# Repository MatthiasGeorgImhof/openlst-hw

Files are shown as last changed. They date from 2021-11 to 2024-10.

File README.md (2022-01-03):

$1K CubeSat Design
==========================

This forked repo adapts the hardware from the OpenLST Reference into something that works for my $1K CubeSat project

**Please note that this repository is desgined to be used as a submodule**, since it depends on symbols & footprints in my [1KCubeSat_Hardware repository](https://github.com/rgw3d/1KCubeSat_Hardware)

Overview
--------

This is an iteration on the OpenLST CC1110 based design, which itself is a simplified version of the TI CC1110 432 MHz reference design.
While the CC1110 can operate over 400-470MHz, this board is designed to operate around 435MHz, within the 435MHz-438MHz US Amateur radio band.
See the [FCC's chart, specifically section 5.282](https://transition.fcc.gov/oet/spectrum/table/fcctable.pdf)

* [Schematic](pdf/openlst-hw.pdf) in PDF form
* [Bill of materials](bom/) with ordering information & datasheet links
* [Gerber files](gerber/osh_park) for PCB fabrication

RF Pipeline
-----------

* **0433BM15A0001 Balun**. Designed for 430-435MHz, but should work up to 437MHz. Single part, designed specifically for the CC1110. I did not want to design my own balun.
* **PE4250MLI RF Switch**. Generic SPDT RF Switch. First RF switch breaks out to a test port. Second RF switch switches between TX & RX paths on the RF Frontend (RFFM6403).
* **RFFM6403 Analog Frontend**. TX path with 1.5W PA, RX path with LNA & SAW filter. Designed to work over the 408-455MHz band.
* **SF2446E SAW Filter**. Part of the Analog Frontend RX path. 430-440MHz band pass.
* 50 Ohm
* Impedance calculations for OSH Park PCB found [here](images/osh-park-4-layer-50ohms.png)

Design Verification
--------

Initial testing has verified basic functionality.

* 437MHz reference software from the [OpenLST Software repo](https://github.com/rgw3d/openlst) is able to be flashed onto the CC1110. NOTE: CC1110 PA output power was modified from 10dBm to 0dBm.
* The 3.3V rail consumes 130mA to 150mA. One board indicated 130mA, another one had 150mA, unsure what causes the discrepency.
* The 27MHz clipped sine wave oscillator works as a clock source
* The RF pipeline is functional. Both the test output (J8) and the RF Frontend output (J9) function.
* Radio-to-radio communication with test outputs connected. Communication was initiated using UART1 on Board 1.
  * (J8, Board 1)---(coax)---(30dBm attenuator)---(coax)---(J8, Board 2)
* Radio-to-radio communication with RF Frontend outputs connected. Communication was initiated using UART1 on Board 1.
  * (J9, Board 1)---(coax)---(three 30dBm attenuators)---(coax)---(J9, Board 2)
* At this time no RF performance characteristics were measured. (I don't have the lab equipment for those tests)

Improvements for future version
--------

* Pi network at output of RF Frontend. Could be useful to match an antenna.
* Better 3.3V LDO. For a bench top setup, U1 (ADP150-3.3V) can just supply 150mA. While this design assumes an external 3.3V source, this on-board convenience ought to be sized up.
* Ferrite beads or 0Ohm Resistors on power inputs to all components. During assembly for one of the boards, a short was detected on the 3.3V rail. Several components share that rail without an easy way to open it, which would have made isolating the problem simple.

Pictures
--------

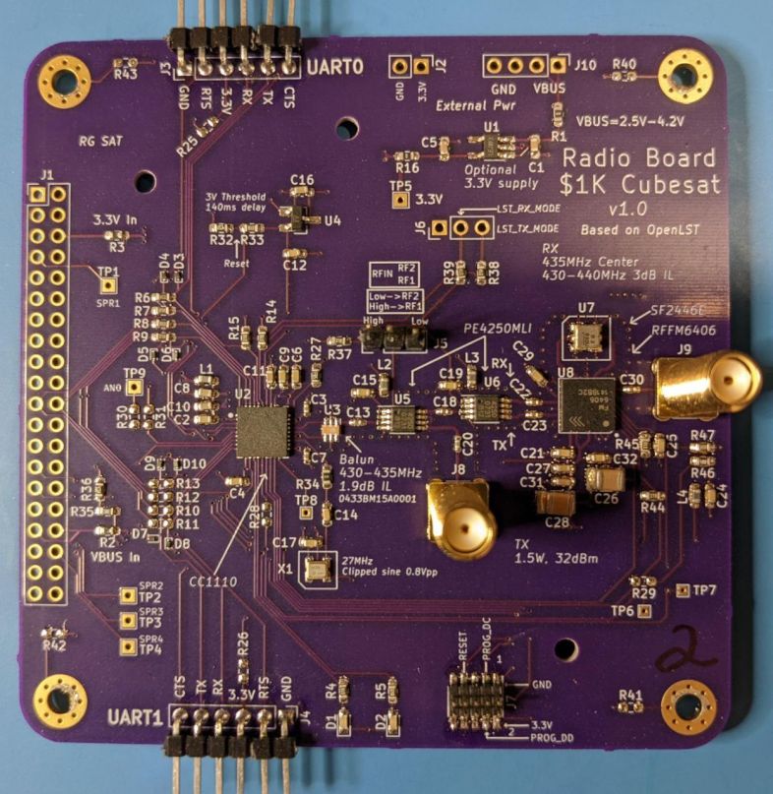
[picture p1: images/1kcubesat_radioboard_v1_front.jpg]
1KCubesat RadioBoard V1 Front

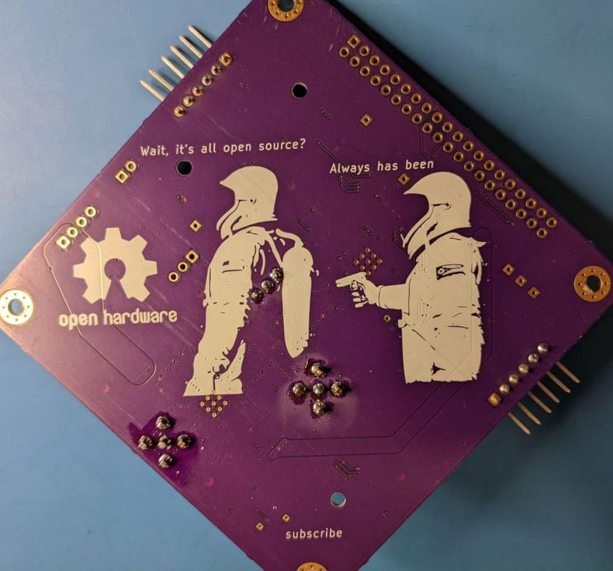
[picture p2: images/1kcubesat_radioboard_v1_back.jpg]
1KCubesat RadioBoard V1 Back


Original README below

OpenLST Reference Hardware
==========================

This repository contains a KiCad project with a hardware reference
implementation for the OpenLST.  This design is a simplified version
of the Texas Instruments CC1110 432 MHz reference design.  A 1 watt
power amplifier module has been added to increase operating range.
The design is intended for use at 437 MHz, however, it may be modified
for use at other frequencies.

The user is responsible for obtaining and maintaining the necessary
license to operate this radio.  The example project uses frequencies
in the US Amateur Radio UHF band. Transmissions in this band require a
valid FCC license and compliance with CFR Part 97.

License & Legal Information
---------------------------

Copyright 2018 Planet Labs Inc. This work is licensed under a
Creative Commons Attribution-ShareAlike 4.0 International License.

This document may contain technology or software the export of which
is or may be restricted by the Export Administration Act and the
Export Administration Regulations (EAR), 15 C.F.R. parts
730-774. Diversion contrary to U.S. law is prohibited.

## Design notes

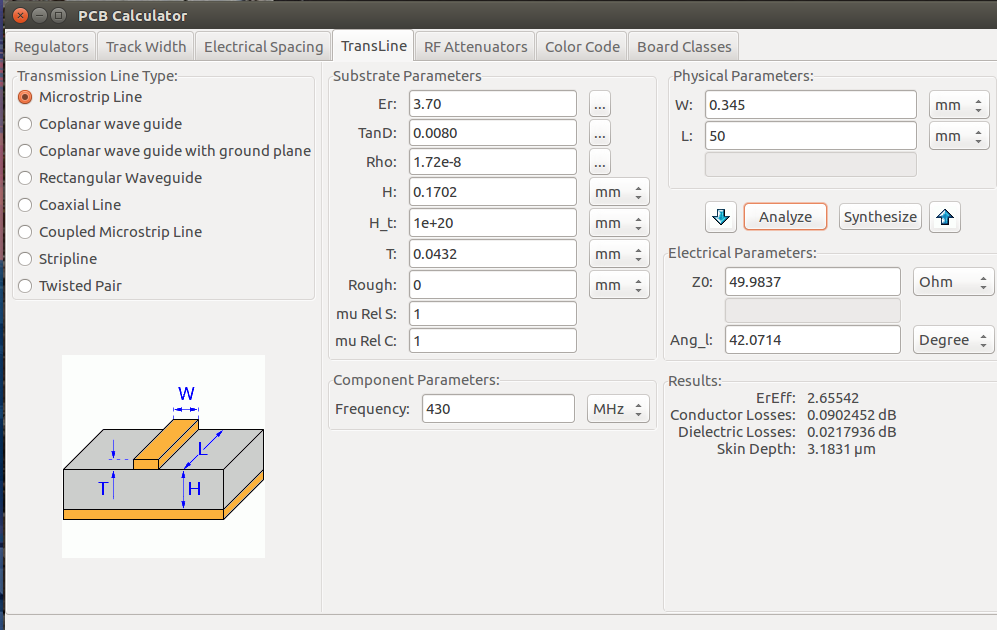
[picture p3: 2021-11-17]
images/osh-park-4-layer-50ohms.png

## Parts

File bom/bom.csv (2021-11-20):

Source: | /home/rgw3d/1KCubeSat_Hardware/openlst-hw/openlst-hw.sch
Date: | Tue 16 Nov 2021 11:39:37 PM EST
Tool: | Eeschema 5.1.7-a382d34a8~88~ubuntu16.04.1
Component Count: | 108
Ref | Value | Part | Footprint | Description | Vendor
C1 | 4.7uF | Device:C_Small | Capacitor_SMD:C_0603_1608Metric_Pad1.08x0.95mm_HandSolder | Unpolarized capacitor, small symbol
C2 | 0.1uF | Device:C_Small | Capacitor_SMD:C_0603_1608Metric_Pad1.08x0.95mm_HandSolder | Unpolarized capacitor, small symbol
C3 | 220pF | openlst-hw:C_Small | Capacitor_SMD:C_0402_1005Metric_Pad0.74x0.62mm_HandSolder
C4 | 0.1uF | Device:C_Small | Capacitor_SMD:C_0603_1608Metric_Pad1.08x0.95mm_HandSolder | Unpolarized capacitor, small symbol
C5 | 4.7uF | Device:C_Small | Capacitor_SMD:C_0603_1608Metric_Pad1.08x0.95mm_HandSolder | Unpolarized capacitor, small symbol
C6 | 0.1uF | Device:C_Small | Capacitor_SMD:C_0603_1608Metric_Pad1.08x0.95mm_HandSolder | Unpolarized capacitor, small symbol
C7 | 220pF | openlst-hw:C_Small | Capacitor_SMD:C_0402_1005Metric_Pad0.74x0.62mm_HandSolder
C8 | 1uF | Device:C_Small | Capacitor_SMD:C_0603_1608Metric_Pad1.08x0.95mm_HandSolder | Unpolarized capacitor, small symbol
C9 | 0.1uF | Device:C_Small | Capacitor_SMD:C_0603_1608Metric_Pad1.08x0.95mm_HandSolder | Unpolarized capacitor, small symbol
C10 | 1uF | Device:C_Small | Capacitor_SMD:C_0603_1608Metric_Pad1.08x0.95mm_HandSolder | Unpolarized capacitor, small symbol
C11 | 1uF | Device:C_Small | Capacitor_SMD:C_0603_1608Metric_Pad1.08x0.95mm_HandSolder | Unpolarized capacitor, small symbol
C12 | 0.01uF | Device:C_Small | Capacitor_SMD:C_0603_1608Metric_Pad1.08x0.95mm_HandSolder | Unpolarized capacitor, small symbol
C13 | 220pF | openlst-hw:C_Small | Capacitor_SMD:C_0402_1005Metric_Pad0.74x0.62mm_HandSolder
C14 | 0.01uF | Device:C_Small | Capacitor_SMD:C_0603_1608Metric_Pad1.08x0.95mm_HandSolder | Unpolarized capacitor, small symbol
C15 | 0.1uF | Device:C_Small | Capacitor_SMD:C_0603_1608Metric_Pad1.08x0.95mm_HandSolder | Unpolarized capacitor, small symbol
C16 | 0.1uF | Device:C_Small | Capacitor_SMD:C_0603_1608Metric_Pad1.08x0.95mm_HandSolder | Unpolarized capacitor, small symbol
C17 | 0.1uF | Device:C_Small | Capacitor_SMD:C_0603_1608Metric_Pad1.08x0.95mm_HandSolder | Unpolarized capacitor, small symbol
C18 | 220pF | openlst-hw:C_Small | Capacitor_SMD:C_0402_1005Metric_Pad0.74x0.62mm_HandSolder
C19 | 0.1uF | Device:C_Small | Capacitor_SMD:C_0603_1608Metric_Pad1.08x0.95mm_HandSolder | Unpolarized capacitor, small symbol
C20 | 220pF | openlst-hw:C_Small | Capacitor_SMD:C_0402_1005Metric_Pad0.74x0.62mm_HandSolder
C21 | 0.1uF | Device:C_Small | Capacitor_SMD:C_0603_1608Metric_Pad1.08x0.95mm_HandSolder | Unpolarized capacitor, small symbol
C22 | 220pF | openlst-hw:C_Small | Capacitor_SMD:C_0402_1005Metric_Pad0.74x0.62mm_HandSolder
C23 | 220pF | openlst-hw:C_Small | Capacitor_SMD:C_0402_1005Metric_Pad0.74x0.62mm_HandSolder
C24 | 0.1uF | Device:C_Small | Capacitor_SMD:C_0603_1608Metric_Pad1.08x0.95mm_HandSolder | Unpolarized capacitor, small symbol
C25 | 0.1uF | Device:C_Small | Capacitor_SMD:C_0603_1608Metric_Pad1.08x0.95mm_HandSolder | Unpolarized capacitor, small symbol
C26 | 47uF | Device:C | Capacitor_SMD:C_1210_3225Metric_Pad1.33x2.70mm_HandSolder | Unpolarized capacitor
C27 | 1uF | Device:C_Small | Capacitor_SMD:C_0603_1608Metric_Pad1.08x0.95mm_HandSolder | Unpolarized capacitor, small symbol
C28 | 47uF | Device:C | Capacitor_SMD:C_1210_3225Metric_Pad1.33x2.70mm_HandSolder | Unpolarized capacitor
C29 | 0.1uF | Device:C_Small | Capacitor_SMD:C_0603_1608Metric_Pad1.08x0.95mm_HandSolder | Unpolarized capacitor, small symbol
C30 | 220pF | openlst-hw:C_Small | Capacitor_SMD:C_0402_1005Metric_Pad0.74x0.62mm_HandSolder
C31 | 4.7uF | Device:C_Small | Capacitor_SMD:C_0603_1608Metric_Pad1.08x0.95mm_HandSolder | Unpolarized capacitor, small symbol
C32 | 0.1uF | Device:C_Small | Capacitor_SMD:C_0603_1608Metric_Pad1.08x0.95mm_HandSolder | Unpolarized capacitor, small symbol
D1 | LED_SMD_RED | Device:LED_Small_ALT | LED_SMD:LED_0603_1608Metric_Pad1.05x0.95mm_HandSolder | Light emitting diode, small symbol, filled shape
D2 | LED_SMD_RED | Device:LED_Small_ALT | LED_SMD:LED_0603_1608Metric_Pad1.05x0.95mm_HandSolder | Light emitting diode, small symbol, filled shape
D3 | ESD9B5.0ST5G | Diode:ESD9B5.0ST5G | Diode_SMD:D_SOD-923 | ESD protection diode, 5.0Vrwm, SOD-923
D4 | ESD9B5.0ST5G | Diode:ESD9B5.0ST5G | Diode_SMD:D_SOD-923 | ESD protection diode, 5.0Vrwm, SOD-923
D5 | ESD9B5.0ST5G | Diode:ESD9B5.0ST5G | Diode_SMD:D_SOD-923 | ESD protection diode, 5.0Vrwm, SOD-923
D6 | ESD9B5.0ST5G | Diode:ESD9B5.0ST5G | Diode_SMD:D_SOD-923 | ESD protection diode, 5.0Vrwm, SOD-923
D7 | ESD9B5.0ST5G | Diode:ESD9B5.0ST5G | Diode_SMD:D_SOD-923 | ESD protection diode, 5.0Vrwm, SOD-923
D8 | ESD9B5.0ST5G | Diode:ESD9B5.0ST5G | Diode_SMD:D_SOD-923 | ESD protection diode, 5.0Vrwm, SOD-923
D9 | ESD9B5.0ST5G | Diode:ESD9B5.0ST5G | Diode_SMD:D_SOD-923 | ESD protection diode, 5.0Vrwm, SOD-923
D10 | ESD9B5.0ST5G | Diode:ESD9B5.0ST5G | Diode_SMD:D_SOD-923 | ESD protection diode, 5.0Vrwm, SOD-923
H1 | MountingHole_Pad | Mechanical:MountingHole_Pad | MountingHole:MountingHole_3.2mm_M3_Pad_Via | Mounting Hole with connection
H2 | MountingHole_Pad | Mechanical:MountingHole_Pad | MountingHole:MountingHole_3.2mm_M3_Pad_Via | Mounting Hole with connection
H3 | MountingHole_Pad | Mechanical:MountingHole_Pad | MountingHole:MountingHole_3.2mm_M3_Pad_Via | Mounting Hole with connection
H4 | MountingHole_Pad | Mechanical:MountingHole_Pad | MountingHole:MountingHole_3.2mm_M3_Pad_Via | Mounting Hole with connection
J1 | Conn_02x20_Odd_Even | Connector_Generic:Conn_02x20_Odd_Even | Connector_PinHeader_2.54mm:PinHeader_2x20_P2.54mm_Vertical | Generic connector, double row, 02x20, odd/even pin numbering scheme (row 1 odd numbers, row 2 even numbers), script generated (kicad-library-utils/schlib/autogen/connector/)
J2 | EXT 3.3V | Connector_Generic:Conn_01x02 | Connector_PinHeader_2.54mm:PinHeader_1x02_P2.54mm_Vertical | Generic connector, single row, 01x02, script generated (kicad-library-utils/schlib/autogen/connector/)
J3 | UART0 | Connector_Generic:Conn_01x06 | Connector_PinHeader_2.54mm:PinHeader_1x06_P2.54mm_Vertical | Generic connector, single row, 01x06, script generated (kicad-library-utils/schlib/autogen/connector/)
J4 | UART1 | Connector_Generic:Conn_01x06 | Connector_PinHeader_2.54mm:PinHeader_1x06_P2.54mm_Vertical | Generic connector, single row, 01x06, script generated (kicad-library-utils/schlib/autogen/connector/)
J5 | Switch Select | Connector_Generic:Conn_01x03 | Connector_PinHeader_2.54mm:PinHeader_1x03_P2.54mm_Vertical | Generic connector, single row, 01x03, script generated (kicad-library-utils/schlib/autogen/connector/)
J6 | Control Outputs | Connector_Generic:Conn_01x03 | Connector_PinHeader_2.54mm:PinHeader_1x03_P2.54mm_Vertical | Generic connector, single row, 01x03, script generated (kicad-library-utils/schlib/autogen/connector/)
J7 | CC Prog/Debug | Connector_Generic:Conn_02x05_Odd_Even | Connector_PinHeader_1.27mm:PinHeader_2x05_P1.27mm_Vertical_SMD | Generic connector, double row, 02x05, odd/even pin numbering scheme (row 1 odd numbers, row 2 even numbers), script generated (kicad-library-utils/schlib/autogen/connector/)
J8 | Conn_Coaxial | Connector:Conn_Coaxial | Connector_Coaxial:SMA_Amphenol_901-144_Vertical | coaxial connector (BNC, SMA, SMB, SMC, Cinch/RCA, ...)
J9 | ANT | Connector:Conn_Coaxial | Connector_Coaxial:SMA_Amphenol_901-144_Vertical | coaxial connector (BNC, SMA, SMB, SMC, Cinch/RCA, ...)
J10 | EXT VBUS | Connector_Generic:Conn_01x04 | Connector_PinHeader_2.54mm:PinHeader_1x04_P2.54mm_Vertical | Generic connector, single row, 01x04, script generated (kicad-library-utils/schlib/autogen/connector/)
L1 | Z=1k @ 100M | openlst-hw:Ferrite_Bead | Inductor_SMD:L_0603_1608Metric_Pad1.05x0.95mm_HandSolder
L2 | Z=1k @ 100M | openlst-hw:Ferrite_Bead | Inductor_SMD:L_0603_1608Metric_Pad1.05x0.95mm_HandSolder
L3 | Z=1k @ 100M | openlst-hw:Ferrite_Bead | Inductor_SMD:L_0603_1608Metric_Pad1.05x0.95mm_HandSolder
L4 | Z=1k @ 100M | openlst-hw:Ferrite_Bead | Inductor_SMD:L_0603_1608Metric_Pad1.05x0.95mm_HandSolder
R1 | DNP | Device:R | Resistor_SMD:R_0603_1608Metric_Pad0.98x0.95mm_HandSolder | Resistor
R2 | 10m | Device:R | Resistor_SMD:R_0603_1608Metric_Pad0.98x0.95mm_HandSolder | Resistor
R3 | 10m | Device:R | Resistor_SMD:R_0603_1608Metric_Pad0.98x0.95mm_HandSolder | Resistor
R4 | 1K | Device:R | Resistor_SMD:R_0603_1608Metric_Pad0.98x0.95mm_HandSolder | Resistor
R5 | 1K | Device:R | Resistor_SMD:R_0603_1608Metric_Pad0.98x0.95mm_HandSolder | Resistor
R6 | 100 | openlst-hw:R | Resistor_SMD:R_0603_1608Metric_Pad0.98x0.95mm_HandSolder
R7 | 100 | openlst-hw:R | Resistor_SMD:R_0603_1608Metric_Pad0.98x0.95mm_HandSolder
R8 | 100 | openlst-hw:R | Resistor_SMD:R_0603_1608Metric_Pad0.98x0.95mm_HandSolder
R9 | 100 | openlst-hw:R | Resistor_SMD:R_0603_1608Metric_Pad0.98x0.95mm_HandSolder
R10 | DNP | Device:R | Resistor_SMD:R_0603_1608Metric_Pad0.98x0.95mm_HandSolder | Resistor
R11 | DNP | Device:R | Resistor_SMD:R_0603_1608Metric_Pad0.98x0.95mm_HandSolder | Resistor
R12 | DNP | Device:R | Resistor_SMD:R_0603_1608Metric_Pad0.98x0.95mm_HandSolder | Resistor
R13 | DNP | Device:R | Resistor_SMD:R_0603_1608Metric_Pad0.98x0.95mm_HandSolder | Resistor
R14 | 1K | Device:R | Resistor_SMD:R_0603_1608Metric_Pad0.98x0.95mm_HandSolder | Resistor
R15 | 1K | Device:R | Resistor_SMD:R_0603_1608Metric_Pad0.98x0.95mm_HandSolder | Resistor
R16 | 0 | Device:R | Resistor_SMD:R_0603_1608Metric_Pad0.98x0.95mm_HandSolder | Resistor
R25 | DNP | Device:R | Resistor_SMD:R_0603_1608Metric_Pad0.98x0.95mm_HandSolder | Resistor
R26 | DNP | Device:R | Resistor_SMD:R_0603_1608Metric_Pad0.98x0.95mm_HandSolder | Resistor
R27 | 56K | openlst-hw:R | Resistor_SMD:R_0603_1608Metric_Pad0.98x0.95mm_HandSolder
R28 | DNP | Device:R | Resistor_SMD:R_0603_1608Metric_Pad0.98x0.95mm_HandSolder | Resistor
R29 | DNP | Device:R | Resistor_SMD:R_0603_1608Metric_Pad0.98x0.95mm_HandSolder | Resistor
R30 | DNP | Device:R | Resistor_SMD:R_0603_1608Metric_Pad0.98x0.95mm_HandSolder | Resistor
R31 | DNP | Device:R | Resistor_SMD:R_0603_1608Metric_Pad0.98x0.95mm_HandSolder | Resistor
R32 | 47K | Device:R | Resistor_SMD:R_0603_1608Metric_Pad0.98x0.95mm_HandSolder | Resistor
R33 | 1K | Device:R | Resistor_SMD:R_0603_1608Metric_Pad0.98x0.95mm_HandSolder | Resistor
R34 | 0 | Device:R | Resistor_SMD:R_0603_1608Metric_Pad0.98x0.95mm_HandSolder | Resistor
R35 | 20K | Device:R | Resistor_SMD:R_0603_1608Metric_Pad0.98x0.95mm_HandSolder | Resistor
R36 | 47K | Device:R | Resistor_SMD:R_0603_1608Metric_Pad0.98x0.95mm_HandSolder | Resistor
R37 | 1K | Device:R | Resistor_SMD:R_0603_1608Metric_Pad0.98x0.95mm_HandSolder | Resistor
R38 | 100 | openlst-hw:R | Resistor_SMD:R_0603_1608Metric_Pad0.98x0.95mm_HandSolder
R39 | 100 | openlst-hw:R | Resistor_SMD:R_0603_1608Metric_Pad0.98x0.95mm_HandSolder
R40 | DNP | Device:R | Resistor_SMD:R_0603_1608Metric_Pad0.98x0.95mm_HandSolder | Resistor
R41 | DNP | Device:R | Resistor_SMD:R_0603_1608Metric_Pad0.98x0.95mm_HandSolder | Resistor
R42 | DNP | Device:R | Resistor_SMD:R_0603_1608Metric_Pad0.98x0.95mm_HandSolder | Resistor
R43 | DNP | Device:R | Resistor_SMD:R_0603_1608Metric_Pad0.98x0.95mm_HandSolder | Resistor
R44 | 1K | Device:R | Resistor_SMD:R_0603_1608Metric_Pad0.98x0.95mm_HandSolder | Resistor
R45 | 1K | Device:R | Resistor_SMD:R_0603_1608Metric_Pad0.98x0.95mm_HandSolder | Resistor
R46 | 3.09K | Device:R | Resistor_SMD:R_0603_1608Metric_Pad0.98x0.95mm_HandSolder | Resistor
R47 | 6.65K | Device:R | Resistor_SMD:R_0603_1608Metric_Pad0.98x0.95mm_HandSolder | Resistor
U1 | ADP150AUJZ-3.3-R7 | 1K_Custom_Symbol:ADP150AUJZ-3.3-R7 | Package_TO_SOT_SMD:TSOT-23-5_HandSoldering
U2 | CC1110 | openlst-hw:CC1110 | openlst:TI_CC_QFN36
U3 | 0433BM15A0001 | Transformer:0433BM15A0001 | RF_Converter:Balun_Johanson_0896BM15A0001 | 430-435MHz 1:1 RF Transformer, Unbalanced to Balanced, with integrated DC blocking capacitor
U4 | MIC803 | 1K_Custom_Symbol:MIC803 | Package_TO_SOT_SMD:SOT-23_Handsoldering
U5 | PE4250MLI | 1K_Custom_Symbol:PE4250MLI | Package_SO:MSOP-8_3x3mm_P0.65mm
U6 | PE4250MLI | 1K_Custom_Symbol:PE4250MLI | Package_SO:MSOP-8_3x3mm_P0.65mm
U7 | SF2446E | 1K_Custom_Symbol:SF2446E | footprint_custom:SF2446E | SAW filter 435MHz
U8 | RFFM6406 | 1K_Custom_Symbol:RFFM6406 | openlst:Qorvo_LGA_28_ThermalVias | Copy of RFFM6403 Symbol from OpenLST Reference
X1 | TG2520SMN 27MHz | 1K_Custom_Symbol:TG2520SMN | footprint_custom:TG2520SMN | 27MHz TCXO Clipped Sine Wave Oscillator 2.8V-3.3V 4-SMD, No Lead

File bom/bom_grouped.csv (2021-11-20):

Reference | Quantity | Value | Footprint | Datasheet | Manuf | ManufPN | Supplier | SupplierPN | Order | Size | Mfr. # | Voltage
C1 C5 C31 | 3 | 4.7uF | Capacitor_SMD:C_0603_1608Metric_Pad1.08x0.95mm_HandSolder | ~ |  |  |  |  |  | 0603 |  | 10V
C12 C14 | 2 | 0.01uF | Capacitor_SMD:C_0603_1608Metric_Pad1.08x0.95mm_HandSolder | ~ |  |  |  |  | https://www.digikey.com/en/products/detail/samsung-electro-mechanics/CL10B103KB8NNNC/3886667 |  | CL10B103KB8NNNC | 50V
C2 C4 C6 C9 C15 C16 C17 C19 C21 C24 C25 C29 C32 | 13 | 0.1uF | Capacitor_SMD:C_0603_1608Metric_Pad1.08x0.95mm_HandSolder | ~ |  |  |  |  | https://www.digikey.com/product-detail/en/samsung-electro-mechanics/CL10B104KA8NNNC/1276-1006-1-ND/3889092 |  | CL10B104KA8NNNC | 25V
C26 C28 | 2 | 47uF | Capacitor_SMD:C_1210_3225Metric_Pad1.33x2.70mm_HandSolder | ~ |  |  |  |  | https://www.digikey.com/product-detail/en/murata-electronics/GRM32EC81C476KE15L/490-10531-1-ND/5026469 | 1210 | GRM32EC81C476KE15L | 16V
C3 C7 C13 C18 C20 C22 C23 C30 | 8 | 220pF | Capacitor_SMD:C_0402_1005Metric_Pad0.74x0.62mm_HandSolder | https://api.kemet.com/component-edge/download/datasheet/C0402C221J2GACAUTO.pdf | Kemet | C0402C221J2GACAUTO | Digikey | 399-11552-1-ND |  | 0402 |  | 200V
C8 C10 C11 C27 | 4 | 1uF | Capacitor_SMD:C_0603_1608Metric_Pad1.08x0.95mm_HandSolder | ~ |  |  |  |  | https://www.digikey.com/product-detail/en/samsung-electro-mechanics/CL10B105KP8NFNC/1276-1945-1-ND/3890031 |  | CL10B105KP8NFNC | 10V
D1 D2 | 2 | LED_SMD_RED | LED_SMD:LED_0603_1608Metric_Pad1.05x0.95mm_HandSolder | https://katalog.we-online.de/led/datasheet/150060RS75000.pdf |  |  |  |  | https://www.digikey.com/product-detail/en/w%C3%BCrth-elektronik/150060RS75000/732-4978-1-ND/4489899 |  | 150060RS75000
D3 D4 D5 D6 D7 D8 D9 D10 | 8 | ESD9B5.0ST5G | Diode_SMD:D_SOD-923 | https://www.onsemi.com/pub/Collateral/ESD9B-D.PDF |  |  |  |  | https://www.digikey.com/product-detail/en/on-semiconductor/ESD9B5-0ST5G/ESD9B5-0ST5GOSCT-ND/1646497 |  | ESD9B5.0ST5G
H1 H2 H3 H4 | 4 | MountingHole_Pad | MountingHole:MountingHole_3.2mm_M3_Pad_Via | ~
J1 | 1 | Conn_02x20_Odd_Even | Connector_PinHeader_2.54mm:PinHeader_2x20_P2.54mm_Vertical | ~ |  |  |  |  | https://www.digikey.com/product-detail/en/samtec-inc/ESQ-120-13-T-D/ESQ-120-13-T-D-ND/7098677 |  | ESQ-120-13-T-D
J10 | 1 | EXT VBUS | Connector_PinHeader_2.54mm:PinHeader_1x04_P2.54mm_Vertical | ~
J2 | 1 | EXT 3.3V | Connector_PinHeader_2.54mm:PinHeader_1x02_P2.54mm_Vertical | ~
J3 | 1 | UART0 | Connector_PinHeader_2.54mm:PinHeader_1x06_P2.54mm_Vertical | ~
J4 | 1 | UART1 | Connector_PinHeader_2.54mm:PinHeader_1x06_P2.54mm_Vertical | ~
J5 | 1 | Switch Select | Connector_PinHeader_2.54mm:PinHeader_1x03_P2.54mm_Vertical | ~
J6 | 1 | Control Outputs | Connector_PinHeader_2.54mm:PinHeader_1x03_P2.54mm_Vertical
J7 | 1 | CC Prog/Debug | Connector_PinHeader_1.27mm:PinHeader_2x05_P1.27mm_Vertical_SMD | https://app.adam-tech.com/products/download/data_sheet/199937/hph2-a-xx-ua-smt-data-sheet.pdf |  |  |  |  | https://www.digikey.com/en/products/detail/adam-tech/HPH2-A-10-UA-SMT/9831541 |  | HPH2-A-10-UA-SMT
J8 | 1 | Conn_Coaxial | Connector_Coaxial:SMA_Amphenol_901-144_Vertical | https://s3-us-west-2.amazonaws.com/catsy.582/C901-144-8RFX.pdf |  |  |  |  | https://www.digikey.com/en/products/detail/amphenol-rf/901-144-8RFX/272189 |  | 901-144-8RFX
J9 | 1 | ANT | Connector_Coaxial:SMA_Amphenol_901-144_Vertical | https://s3-us-west-2.amazonaws.com/catsy.582/C901-144-8RFX.pdf |  |  |  |  | https://www.digikey.com/en/products/detail/amphenol-rf/901-144-8RFX/272189 |  | 901-144-8RFX
L1 L2 L3 L4 | 4 | Z=1k @ 100M | Inductor_SMD:L_0603_1608Metric_Pad1.05x0.95mm_HandSolder | http://katalog.we-online.de/pbs/datasheet/74279266.pdf |  |  |  |  | https://www.digikey.com/en/products/detail/murata-electronics/BLM18AG102SN1D/584226 |  | BLM18AG102SN1D
R16 R34 | 2 | 0 | Resistor_SMD:R_0603_1608Metric_Pad0.98x0.95mm_HandSolder | ~ |  |  |  |  |  | 0603
R2 R3 | 2 | 10m | Resistor_SMD:R_0603_1608Metric_Pad0.98x0.95mm_HandSolder | ~ |  |  |  |  | https://www.digikey.com/product-detail/en/panasonic-electronic-components/ERJ-3LWJR010V/P19190CT-ND/6004545 | 0603 | ERJ-3LWJR010V
R27 | 1 | 56K | Resistor_SMD:R_0603_1608Metric_Pad0.98x0.95mm_HandSolder | https://www.seielect.com/Catalog/SEI-RMCF_RMCP.pdf | YAGEO | RC0603JR-0756KL | Digikey | 311-56KGRCT-ND | https://www.digikey.com/en/products/detail/yageo/RC0603JR-0756KL/726808 | 0603
R32 R36 | 2 | 47K | Resistor_SMD:R_0603_1608Metric_Pad0.98x0.95mm_HandSolder | https://www.bourns.com/docs/Product-Datasheets/CHPREZTR.pdf |  |  |  |  | https://www.digikey.com/product-detail/en/bourns-inc/CR0603-FX-4702ELF/CR0603-FX-4702ELFCT-ND/3925317 | 0603 | CR0603-FX-4702ELF
R35 | 1 | 20K | Resistor_SMD:R_0603_1608Metric_Pad0.98x0.95mm_HandSolder | ~ |  |  |  |  | https://www.digikey.com/en/products/detail/stackpole-electronics-inc/RMCF0603FT20K0/1760829 | 0603 | RMCF0603FT20K0
R6 R7 R8 R9 R38 R39 | 6 | 100 | Resistor_SMD:R_0603_1608Metric_Pad0.98x0.95mm_HandSolder | https://www.seielect.com/catalog/sei-rmcf_rmcp.pdf | Stackpole Electronics Inc |  | Digikey | RMCF0603FG100RCT-ND | https://www.digikey.com/en/products/detail/stackpole-electronics-inc/RMCF0603FG100R/1713541 | 0603 | RMCF0603FG100R
R4 R5 R14 R15 R33 R37 R44 R45 | 8 | 1K | Resistor_SMD:R_0603_1608Metric_Pad0.98x0.95mm_HandSolder | ~ |  |  |  |  | https://www.digikey.com/en/products/detail/stackpole-electronics-inc/RMCF0603FT1K00/1942996 | 0603 | RMCF0603FT1K00
R1 R10 R11 R12 R13 R25 R26 R28 R29 R30 R31 R40 R41 R42 R43 | 15 | DNP | Resistor_SMD:R_0603_1608Metric_Pad0.98x0.95mm_HandSolder | ~ |  |  |  |  |  | 0603
R46 | 1 | 3.09K | Resistor_SMD:R_0603_1608Metric_Pad0.98x0.95mm_HandSolder | ~ |  |  |  |  | https://www.digikey.com/en/products/detail/stackpole-electronics-inc/RMCF0603FT3K09/1761340 | 0603 | RMCF0603FT3K09
R47 | 1 | 6.65K | Resistor_SMD:R_0603_1608Metric_Pad0.98x0.95mm_HandSolder | https://www.seielect.com/catalog/sei-rmcf_rmcp.pdf |  |  |  |  | https://www.digikey.com/en/products/detail/stackpole-electronics-inc/RMCF0603FT6K65/1760771 | 0603 | RMCF0603FT6K65
TP1 TP2 TP3 TP4 TP5 TP9 | 6 | TP_1.5x1.5 | TestPoint:TestPoint_THTPad_1.5x1.5mm_Drill0.7mm | ~
TP6 TP7 TP8 | 3 | TP_tht_1x1 | TestPoint:TestPoint_THTPad_1.0x1.0mm_Drill0.5mm | ~
U1 | 1 | ADP150AUJZ-3.3-R7 | Package_TO_SOT_SMD:TSOT-23-5_HandSoldering | https://www.analog.com/media/en/technical-documentation/data-sheets/ADP150.pdf
U2 | 1 | CC1110 | openlst:TI_CC_QFN36 | http://www.ti.com/lit/ds/symlink/cc1110-cc1111.pdf | Texas Instruments | CC1110F32RHHR | Digikey | 296-38560-1-ND
U3 | 1 | 0433BM15A0001 | RF_Converter:Balun_Johanson_0896BM15A0001 | https://www.johansontechnology.com/datasheets/0433BM15A0001/0433BM15A0001.pdf |  |  |  |  | https://www.digikey.com/en/products/detail/johanson-technology-inc/0433BM15A0001E/2764673 |  | 0433BM15A0001E
U4 | 1 | MIC803 | Package_TO_SOT_SMD:SOT-23_Handsoldering | https://ww1.microchip.com/downloads/en/DeviceDoc/MIC803-3-Pin-Microprocessor-Supervisor-Circuit-with-Open-Drain-Reset-Output-DS20006456A.pdf |  |  |  |  | https://www.digikey.com/en/products/detail/microchip-technology/MIC803-30D3VM3-TR/2566987 |  | MIC803-30D3VM3-TR
U5 U6 | 2 | PE4250MLI | Package_SO:MSOP-8_3x3mm_P0.65mm | https://www.psemi.com/pdf/datasheets/pe4250ds.pdf |  |  |  |  | https://www.digikey.com/en/products/detail/psemi/PE4250MLI-Z/2614479 |  | PE4250MLI-Z
U7 | 1 | SF2446E | footprint_custom:SF2446E | https://www.rfmi.co/pdf/Datasheet/sf2446e.pdf |  |  |  |  | https://www.digikey.com/en/products/detail/rfmi/SF2446E/12178506 |  | SF2446E
U8 | 1 | RFFM6406 | openlst:Qorvo_LGA_28_ThermalVias | https://www.qorvo.com/products/d/da000807 |  |  |  |  | https://www.mouser.com/ProductDetail/772-RFFM6406SR
X1 | 1 | TG2520SMN 27MHz | footprint_custom:TG2520SMN | https://support.epson.biz/td/api/doc_check.php?dl=brief_TG2520SMN&lang=en |  |  |  |  | https://www.digikey.com/en/products/detail/epson/TG2520SMN-27-0000M-MCGNNM3/13151956 |  | TG2520SMN 27.0000M-MCGNNM3

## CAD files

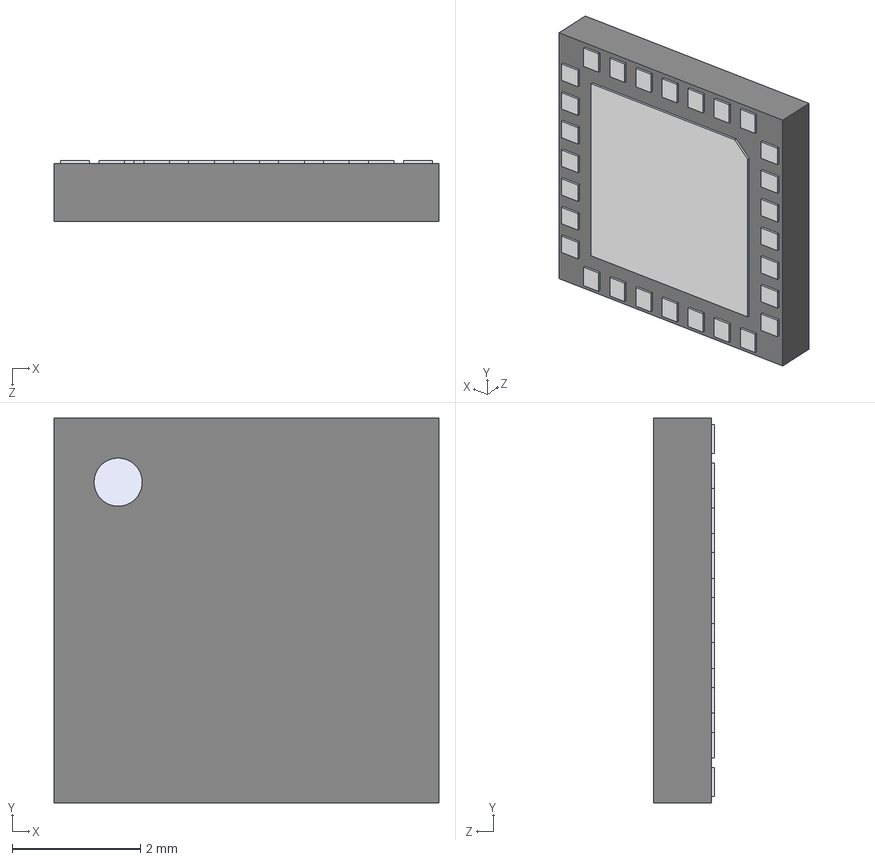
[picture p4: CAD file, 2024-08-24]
step3d/LGA-28-6x6-0.7x0.7.step
6.00 x 6.00 x 0.95 mm
Open_CASCADE_STEP_translator_6.8_27.1
Open_CASCADE_STEP_translator_6.8_27.2.1
Thermal_Shape
Pin_Shape x 28

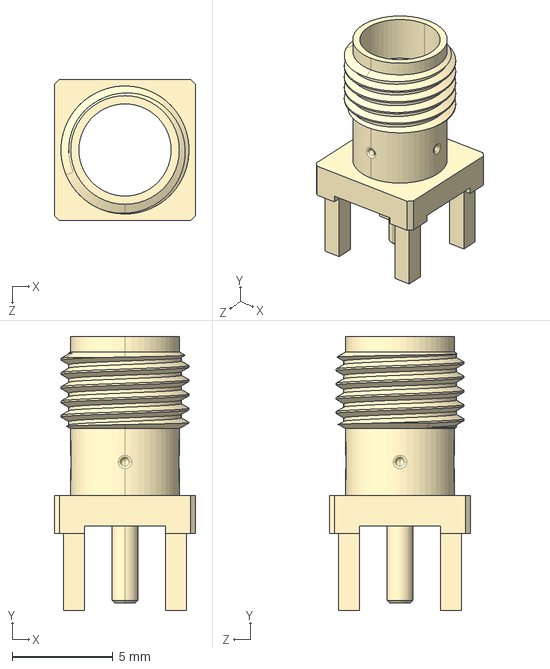
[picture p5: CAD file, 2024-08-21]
step3d/CONSMA001-G.step
7.01 x 13.6 x 7.01 mm

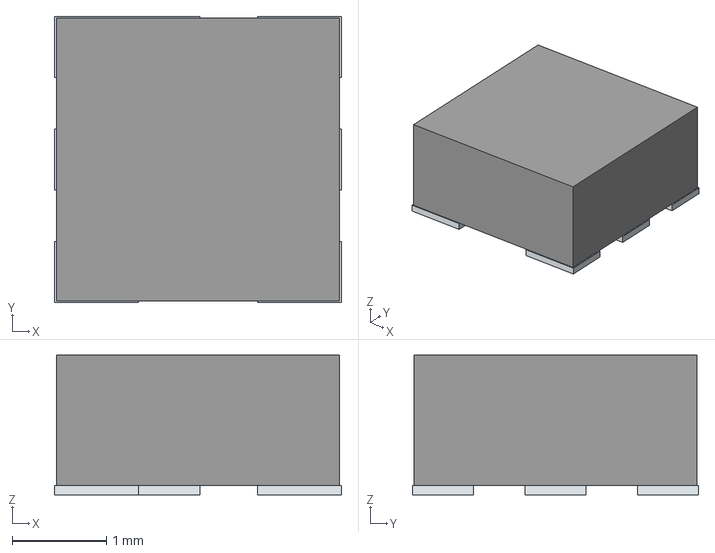
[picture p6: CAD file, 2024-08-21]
step3d/SF2446E.stp
3.04 x 3.03 x 1.48 mm
Pins

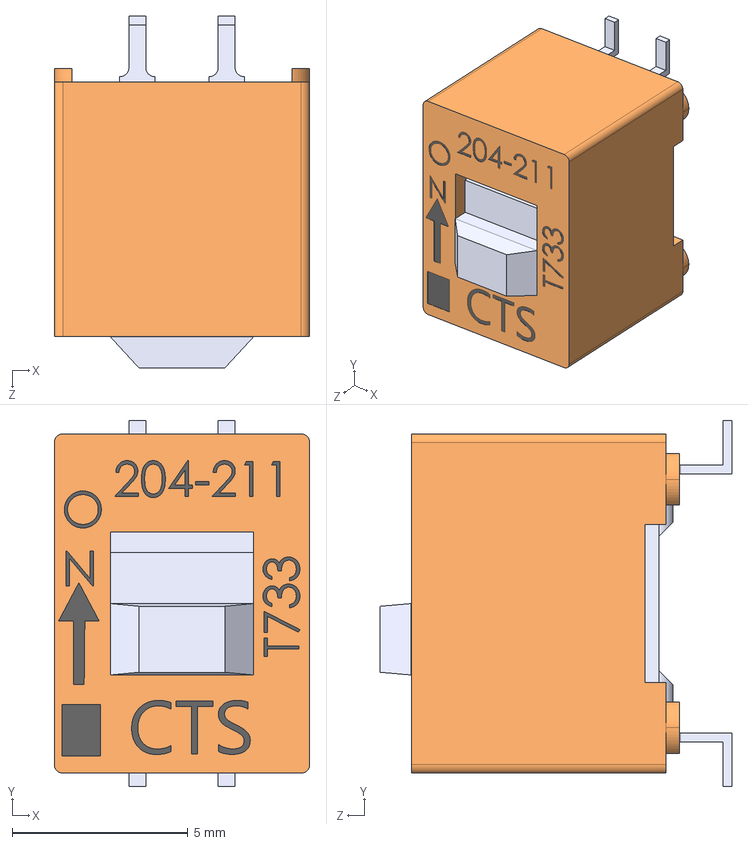
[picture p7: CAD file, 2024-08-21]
step3d/204-211.step
7.27 x 10.4 x 10.0 mm
204-211R cover
204-211 actuator
204-2 pole assembly

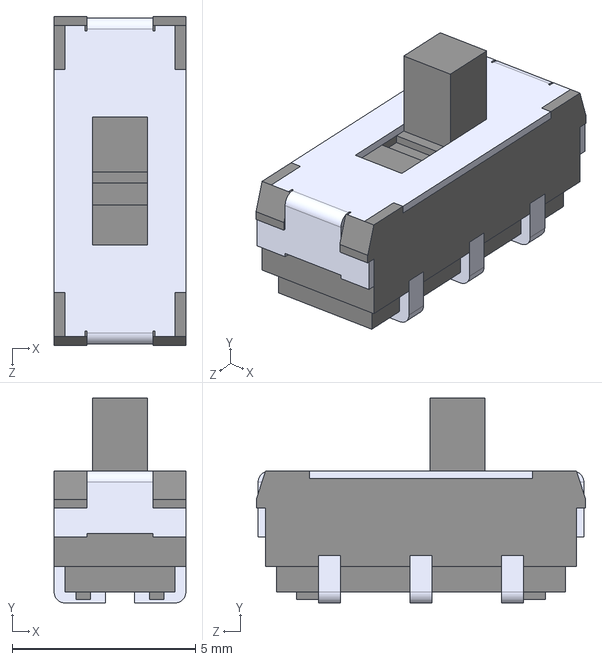
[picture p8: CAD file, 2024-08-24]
step3d/JS202011JCQN.step
3.60 x 5.60 x 9.00 mm

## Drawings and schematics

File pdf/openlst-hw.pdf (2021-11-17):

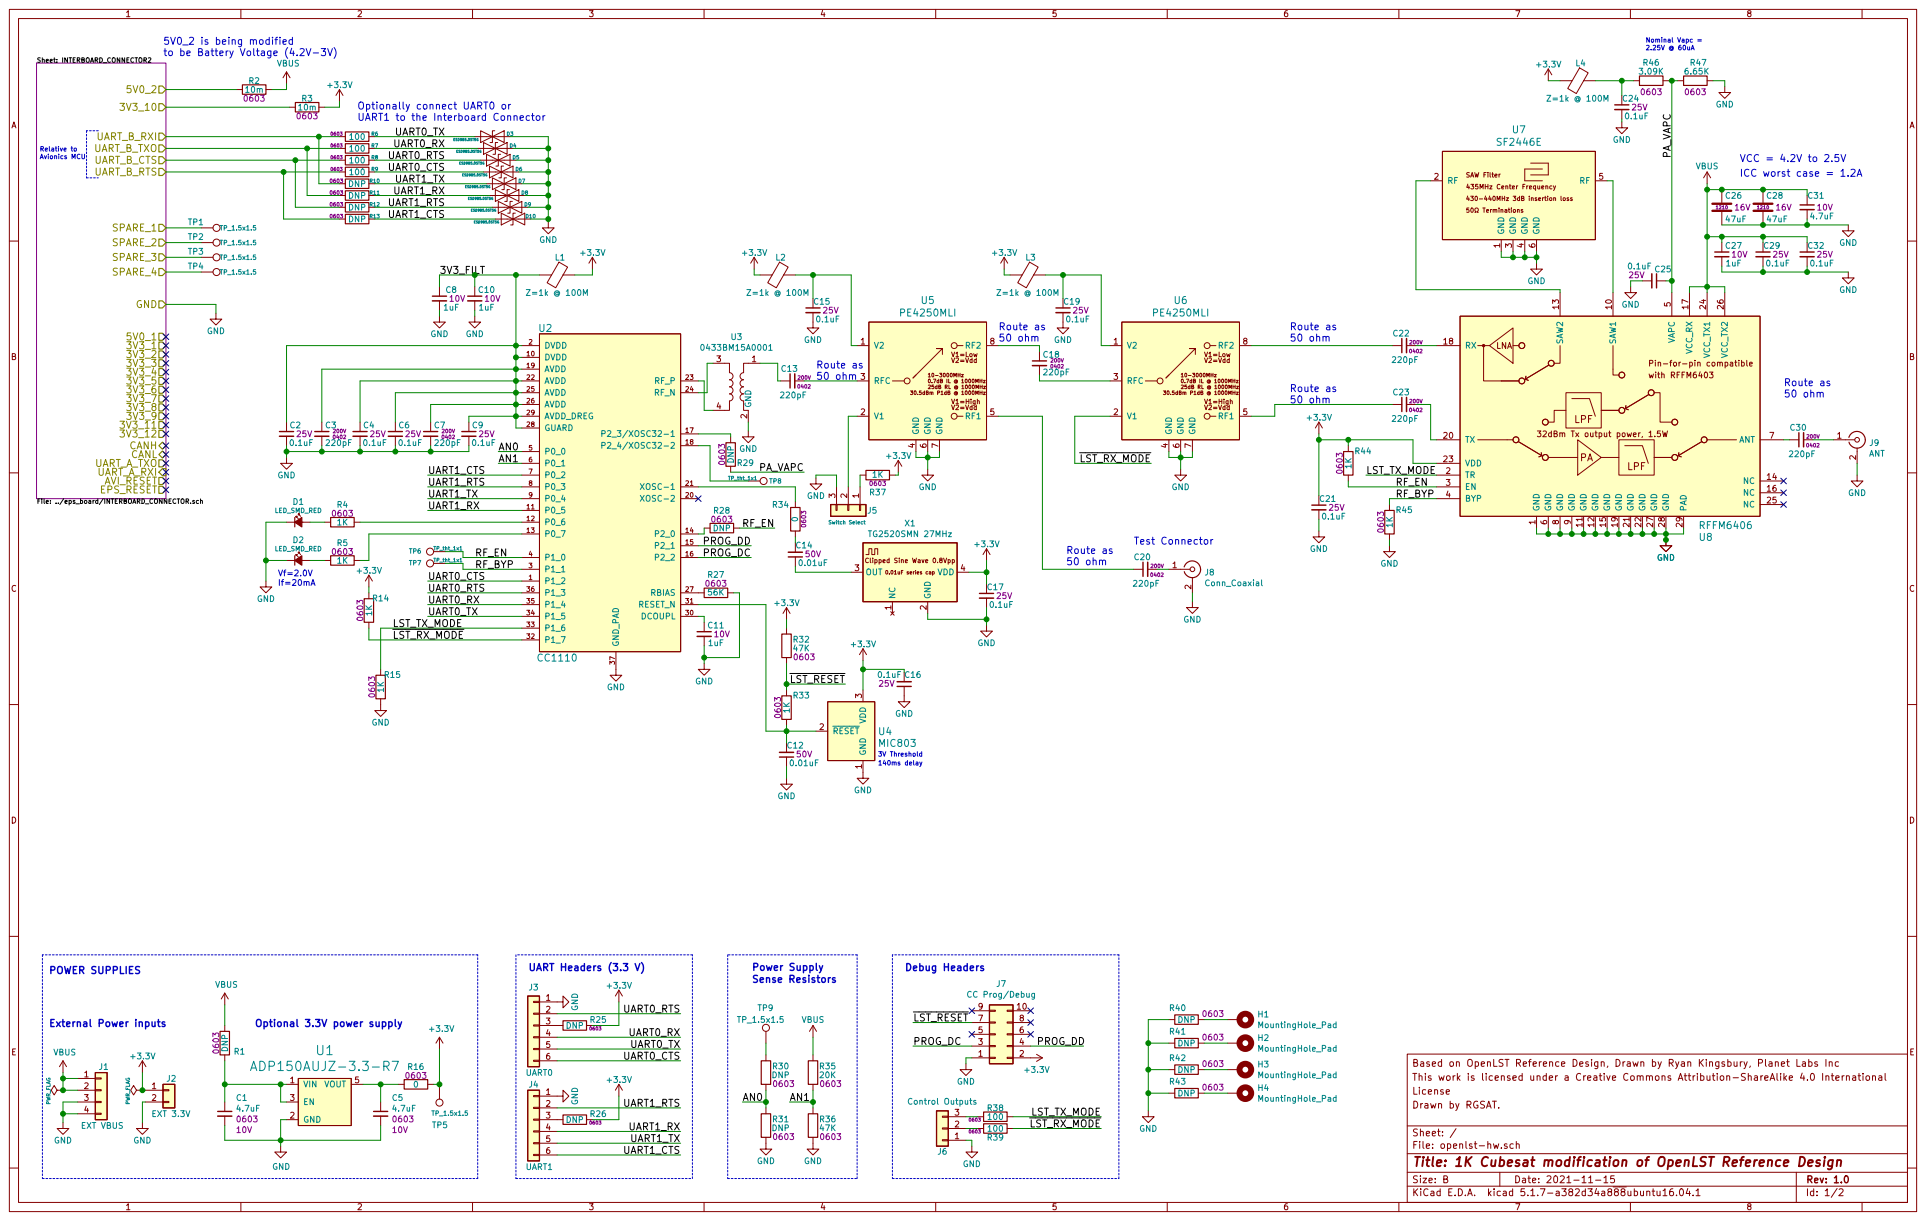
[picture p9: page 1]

5V0_2 is being modified
to be Battery Voltage (4.2V-3V)

Nominal Vapc = 2.25V @ 60uA
ICC worst case = 1.2A Route as 50 ohm

Optionally connect UART0 or
UART1 to the Interboard Connector

Relative to Avionics MCU

7 RF2 8 U6 PE4250MLI VBUS GND GND DNP R29 0603 GND

435MHz Center Frequency 430-440MHz 3dB insertion loss 50 Terminations SAW Filter GND

2 OUT 3 VDD 4 X1 TG2520SMN 27MHz GND GND

Pin-for-pin compatible with RFFM6403 GND

0.01uF series cap Clipped Sine Wave 0.8Vpp NC

If=20mA External Power inputs

140ms delay Optional 3.3V power supply

File: openlst-hw.sch Sheet: / Drawn by RGSAT. License This work is licensed under a Creative Commons Attribution-ShareAlike 4.0 International Based on OpenLST Reference Design, Drawn by Ryan Kingsbury, Planet Labs Inc

LST_RX_MODE

UART1_TX 5

UART1_RX

Id: 1/2 Title: 1K Cubesat modification of OpenLST Reference Design

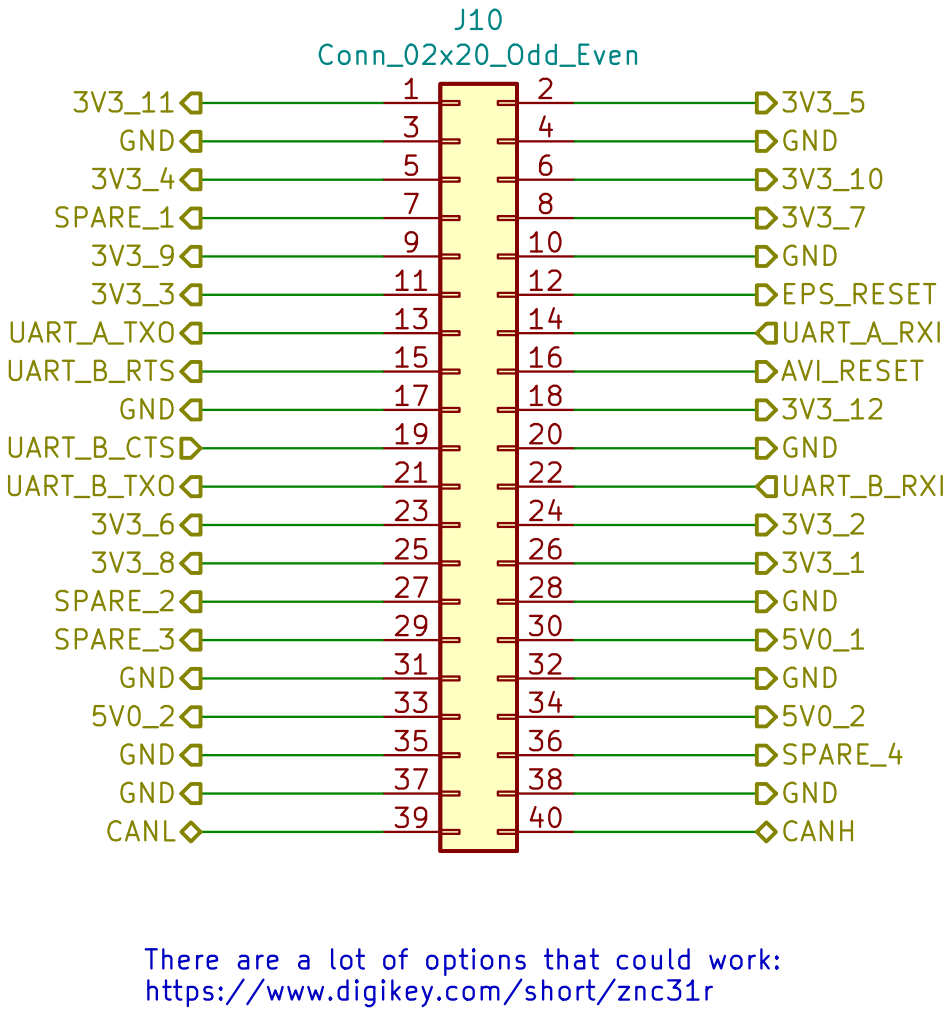
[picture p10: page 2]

3V3_8 There are a lot of options that could work:

https://www.digikey.com/short/znc31r

Sheet: /INTERBOARD_CONNECTOR2/
File: INTERBOARD_CONNECTOR.sch
Id: 2/2 Title: Current Monitor

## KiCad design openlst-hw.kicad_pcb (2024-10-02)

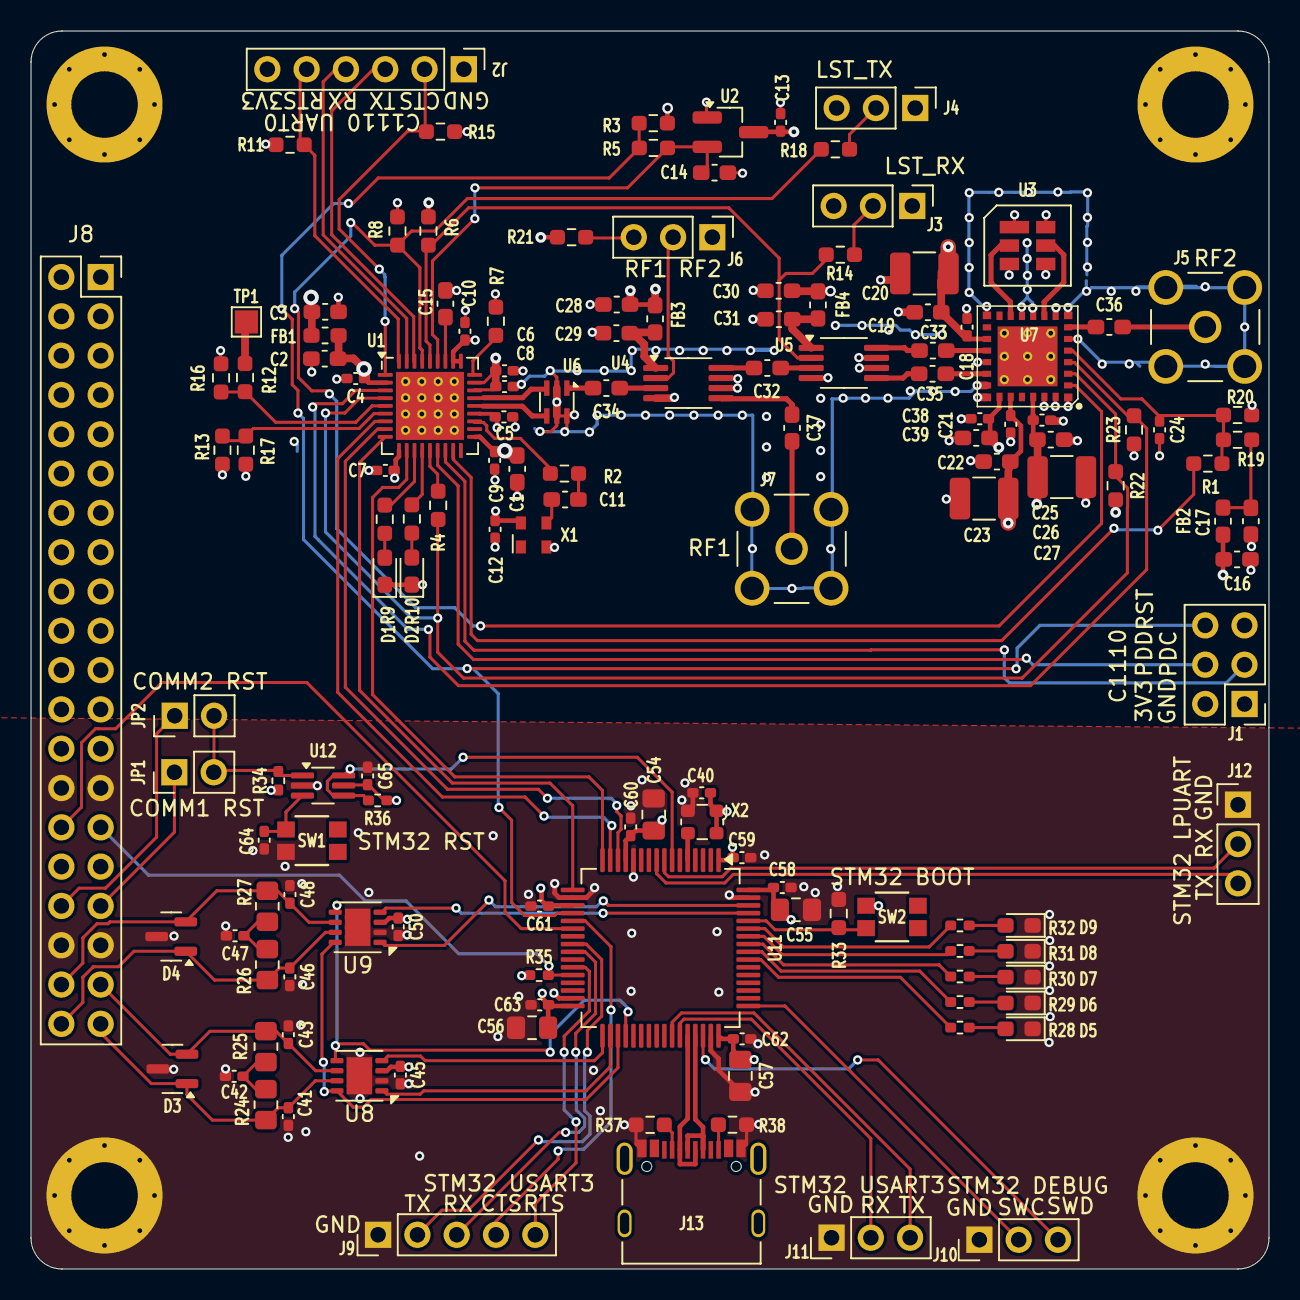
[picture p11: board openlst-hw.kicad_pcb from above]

Board: 4 copper layers, 80.0 x 80.0 mm, 146 parts (0 on the bottom side), 104 nets.

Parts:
C1, C19, C22, C26, C39: 10u; C_0603_1608Metric_Pad1.08x0.95mm_HandSolder
C2, C3, C15, C16, C17, C28, C29, C30, C31: 1u; C_0603_1608Metric_Pad1.08x0.95mm_HandSolder
C4, C5, C6, C7, C8, C9, C10, C12, C13, C18, C21, C24, C25, C38, C40, C45, C50, C58, C59, C60, C61, C62, C63, C64, C65: 100n; C_0402_1005Metric_Pad0.74x0.62mm_HandSolder
C11, C14: 10n; C_0603_1608Metric_Pad1.08x0.95mm_HandSolder
C20, C23, C27: 47u; C_1210_3225Metric_Pad1.33x2.70mm_HandSolder
C32, C33, C34, C35, C36, C37: 220p; C_0603_1608Metric_Pad1.08x0.95mm_HandSolder
C41, C43, C46, C48: 100p; C_0402_1005Metric_Pad0.74x0.62mm_HandSolder
C42, C47: 4.7n; C_0402_1005Metric_Pad0.74x0.62mm_HandSolder
C54, C55, C56, C57: 10u; C_0805_2012Metric_Pad1.18x1.45mm_HandSolder
D1, D2: ORANGE; LED_0603_1608Metric_Pad1.05x0.95mm_HandSolder
D3, D4: NUP2105L; SOT-23
D5: LED_SMD_RED; LED_0603_1608Metric_Pad1.05x0.95mm_HandSolder
D6: LED_SMD_GREEN; LED_0603_1608Metric_Pad1.05x0.95mm_HandSolder
D7, D8, D9: LED_SMD_YELLOW; LED_0603_1608Metric_Pad1.05x0.95mm_HandSolder
FB1, FB2, FB3, FB4: Z=1k @ 100M; L_0603_1608Metric_Pad1.05x0.95mm_HandSolder
H1, H2, H3, H4: MountingHole_Pad; MountingHole_4.3mm_M4_Pad_Via_Custom
J1: CC Prog/Debug; PinHeader_2x03_P2.54mm_Vertical
J2: UART0; PinHeader_1x06_P2.54mm_Vertical
J3, J4: Control Outputs; PinHeader_1x03_P2.54mm_Vertical
J5: ANT; LINX_CONSMA001-G
J6: Switch Select; PinHeader_1x03_P2.54mm_Vertical
J7: Conn_Coaxial; LINX_CONSMA001-G
J8: PC104 Conn_02x20_Odd_Even; PinSocket_2x20_P2.54mm_Vertical
J9: Conn_01x05_Pin; PinHeader_1x05_P2.54mm_Vertical
J10, J11, J12: Conn_01x03_Pin; PinHeader_1x03_P2.54mm_Vertical
J13: 10155435-00011LF; AMPHENOL_10155435-00011LF
JP1, JP2: Jumper_2_Open; PinHeader_1x02_P2.54mm_Vertical
R1, R2, R4: 0; R_0603_1608Metric_Pad0.98x0.95mm_HandSolder
R3, R17: 47K; R_0603_1608Metric_Pad0.98x0.95mm_HandSolder
R5, R6, R8, R22, R23: 1K; R_0603_1608Metric_Pad0.98x0.95mm_HandSolder
R7: 56K; R_0603_1608Metric_Pad0.98x0.95mm_HandSolder
R9, R10: 680; R_0603_1608Metric_Pad0.98x0.95mm_HandSolder
R11, R15: 100K; R_0603_1608Metric_Pad0.98x0.95mm_HandSolder
R12, R16: DNP; R_0603_1608Metric_Pad0.98x0.95mm_HandSolder
R13, R21: 20K; R_0603_1608Metric_Pad0.98x0.95mm_HandSolder
R14, R18: 22; R_0603_1608Metric_Pad0.98x0.95mm_HandSolder
R19: 3.09K; R_0603_1608Metric_Pad0.98x0.95mm_HandSolder
R20: 6.65K; R_0603_1608Metric_Pad0.98x0.95mm_HandSolder
R24, R25, R26, R27: 60R4; R_0805_2012Metric_Pad1.20x1.40mm_HandSolder
R28, R29, R30, R31, R32: 680; R_0402_1005Metric_Pad0.72x0.64mm_HandSolder
R33: 10k; R_0603_1608Metric_Pad0.98x0.95mm_HandSolder
R34, R35, R36: 100K; R_0402_1005Metric_Pad0.72x0.64mm_HandSolder
R37, R38: 5K1; R_0603_1608Metric_Pad0.98x0.95mm_HandSolder
SW1, SW2: EVP-AA602W; EVP602AA
TP1: TestPoint; TestPoint_Pad_1.5x1.5mm
U1: CC1110; Texas_RHH0036C_VQFN-36-1EP_6x6mm_P0.5mm_EP4.4x4.4mm_Thermal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
U2: MIC803; SOT-23_Handsoldering
U3: SF2446E
U4, U5: PE4250MLI; MSOP-8_3x3mm_P0.65mm
U6: 0433BM15A0001; Balun_Johanson_0896BM15A0001
U7: RFFM6406
U8, U9: TCAN3414; VSON-8-1EP_3x3mm_P0.65mm_EP1.65x2.4mm
U11: STM32L496RGTx; LQFP-64_10x10mm_P0.5mm
U12: 74LVC2G07; SOT-363_SC-70-6_Handsoldering
X1: 27MHz; Oscillator_SMD_Abracon_ASDMB-4Pin_2.5x2.0mm
X2: 10MHz; Oscillator_SMD_ECS_2520MV-xxx-xx-4Pin_2.5x2.0mm

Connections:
/CAN Bridge/ATTENTION: J8.29, R35.2, U11.28 (PB2)
/CAN Bridge/CAN1_H: C46.1, D4.1 (K), J8.40, R26.1, U9.7 (CANH)
/CAN Bridge/CAN1_L: C48.2, D4.2 (K), J8.38, R27.2, U9.6 (CANL)
/CAN Bridge/CAN2_H: C41.1, D3.1 (K), J8.39, R24.1, U8.7 (CANH)
/CAN Bridge/CAN2_L: C43.2, D3.2 (K), J8.37, R25.2, U8.6 (CANL)
/CAN Bridge/CAN Transceiver1/CAN_RX: U9.4 (RXD), U11.61 (PB8)
/CAN Bridge/CAN Transceiver1/CAN_TX: U9.1 (TXD), U11.62 (PB9)
/CAN Bridge/CAN Transceiver1/SHDN: U8.5 (SHTD), U9.5 (SHTD), U11.36 (PB15)
/CAN Bridge/CAN Transceiver2/CAN_RX: U8.4 (RXD), U11.33 (PB12)
/CAN Bridge/CAN Transceiver2/CAN_TX: U8.1 (TXD), U11.34 (PB13)
/CAN Bridge/CAN_RS: U8.8 (STB), U9.8 (STB), U11.35 (PB14)
/CAN Bridge/COMM1_RST: J8.33, JP1.1 (A)
/CAN Bridge/COMM2_RST: J8.34, JP2.1 (A)
/CAN Bridge/EPS_RST: J8.30, U11.22 (PA6)
/CAN Bridge/PMIC/EXTR_RST: JP1.2 (B), JP2.2 (B), R34.2, U12.1 (IN1)
/CAN Bridge/PMIC/HSE_IN: U11.5 (PH0), X2.3 (OUTPUT)
/CAN Bridge/PMIC/LED1: R28.2, U11.55 (PB3)
/CAN Bridge/PMIC/LED2: R29.2, U11.56 (PB4)
/CAN Bridge/PMIC/LED3: R30.2, U11.57 (PB5)
/CAN Bridge/PMIC/LED4: R31.2, U11.58 (PB6)
/CAN Bridge/PMIC/LED5: R32.2, U11.59 (PB7)
/CAN Bridge/PMIC/LPUART_RX: J12.2, U11.8 (PC0)
/CAN Bridge/PMIC/LPUART_TX: J12.3, U11.9 (PC1)
/CAN Bridge/PMIC/SYS_JTMS_SWCLK: J10.2, U11.49 (PA14)
/CAN Bridge/PMIC/SYS_JTMS_SWDIO: J10.3, U11.46 (PA13)
/CAN Bridge/PMIC/Schmitt Trigger/IN2: C64.1, SW1.3, U12.3 (IN2)
/CAN Bridge/PMIC/Schmitt Trigger/OUT: R36.2, U11.7 (NRST), U12.4 (OUT2), U12.6 (OUT1)
/CAN Bridge/PMIC/USART1_RX: J11.2, U11.43 (PA10)
/CAN Bridge/PMIC/USART1_TX: J11.3, U11.42 (PA9)
/CAN Bridge/PMIC/USART3_CTS: J9.4, U11.21 (PA5)
/CAN Bridge/PMIC/USART3_RTS: J9.5, U11.27 (PB1)
/CAN Bridge/PMIC/USART3_RX: J9.3, U11.25 (PC5)
/CAN Bridge/PMIC/USART3_TX: J9.2, U11.24 (PC4)
/CAN Bridge/PMIC/USB/USB_OTG_FS_DM: J13.A7 (DN1_A), J13.B7 (DN2_B), U11.44 (PA11)
/CAN Bridge/PMIC/USB/USB_OTG_FS_DP: J13.A6 (DP1_A), J13.B6 (DP2_B), U11.45 (PA12)
/CAN Bridge/UART_CTS: U1.8 (P0_3), U11.14 (PA0)
/CAN Bridge/UART_RTS: U1.7 (P0_2), U11.15 (PA1)
/CAN Bridge/UART_RX: U1.9 (P0_4), U11.17 (PA3)
/CAN Bridge/UART_TX: U1.11 (P0_5), U11.16 (PA2)
/INTERBOARD_CONNECTOR2/3V3_17_RF1_BRIDGE: C40.1, C45.1, C50.1, C54.1, C55.1, C56.1, C57.1, C58.1, C59.1, C60.1, C61.1, C62.1, C63.1, C65.2, J8.23, R34.1, R35.1, R36.1, SW2.3, U8.3 (VCC), U9.3 (VCC), U11.1 (VBAT), U11.13 (VDDA), U11.19 (VDD), U11.32 (VDD), U11.48 (VDDUSB), U11.64 (VDD), U12.5 (VCC), X2.1 (TRI-STATE), X2.4 (VDD)
/INTERBOARD_CONNECTOR2/3V3_18_RF1_COMM: C3.1, C12.1, C13.2, C16.1, C28.1, C30.1, C38.1, C39.1, FB1.1, FB2.2, FB3.2, FB4.2, J1.2, J2.6, J3.3, J4.3, J8.24, R3.2, R6.2, R21.1, R22.2, U2.3 (VCC), U7.23 (VDD), X1.4 (Vcc)
/INTERBOARD_CONNECTOR2/BATT_1_COMM1_VRF: C18.1, C19.1, C20.1, C21.1, C22.1, C23.1, C25.1, C26.1, C27.1, J8.3, R13.2, U7.17 (VCC_RX), U7.24 (VCC_TX1), U7.26 (VCC_TX2)
/MCU/+3V3_C1110: C1.1, C2.1, C4.1, C5.1, C6.1, C7.1, C8.1, C9.1, C10.1, FB1.2, U1.2 (DVDD), U1.10 (DVDD), U1.19 (AVDD), U1.22 (AVDD), U1.25 (AVDD), U1.26 (AVDD), U1.28 (GUARD), U1.29 (AVDD_DREG)
/MCU/AN0: R12.1, R16.2, U1.5 (P0_0)
/MCU/AN1: R13.1, R17.2, U1.6 (P0_1)
/MCU/LST_RX_MODE: R6.1, R14.1, U1.32 (P1_7), U5.2 (V1)
/MCU/LST_TX_MODE: R8.2, R18.1, U1.33 (P1_6), U7.2 (TR)
/MCU/PA_VAPC: C24.1, R1.2, R19.2, R20.1, U7.5 (VAPC)
/MCU/RF_BYP: R23.2, U1.3 (P1_1), U7.4 (BYP)
/MCU/RF_EN: R4.2, R22.1, U1.4 (P1_0), U7.3 (EN)
/MCU/RF_N: U1.24 (RF_N), U6.3
/MCU/RF_P: U1.23 (RF_P), U6.4
/MCU/UART0_CTS: J2.2, R15.2, U1.1 (P1_2)
/MCU/UART0_RTS: J2.5, R11.2, U1.36 (P1_3)
/MCU/UART0_RX: J2.4, U1.35 (P1_4)
/MCU/UART0_TX: J2.3, U1.34 (P1_5)
GND: C1.2, C2.2, C3.2, C4.2, C5.2, C6.2, C7.2, C8.2, C9.2, C10.2, C12.2, C13.1, C14.1, C15.2, C16.2, C17.2, C18.2, C19.2, C20.2, C21.2, C22.2, C23.2, C24.2, C25.2, C26.2, C27.2, C28.2, C29.2, C30.2, C31.2, C38.2, C39.2, C40.2, C41.2, C42.2, C43.1, C45.2, C46.2, C47.2, C48.1, C50.2, C54.2, C55.2, C56.2, C57.2, C58.2, C59.2, C60.2, C61.2, C62.2, C63.2, C64.2, C65.1, D1.1 (K), D2.1 (K), D3.3 (A), D4.3 (A), D5.1 (K), D6.1 (K), D7.1 (K), D8.1 (K), D9.1 (K), H1.1, H2.1, H3.1, H4.1, J1.1, J2.1, J3.1, J4.1, J5.2 (Ext), J6.1, J7.2 (Ext), J8.1, J8.2, J8.27, J8.28, J8.35, J8.36, J9.1, J10.1, J11.1, J12.1, J13.A1_B12 (GND), J13.B1_A12 (GND__1), R7.1, R8.1, R11.1, R15.1, R16.1, R17.1, R20.2, R23.1, R33.2, R37.2, R38.1, SW1.4, U1.37 (GND_PAD), U2.1 (GND), U3.1 (GND), U3.3 (GND), U3.4 (GND), U3.6 (GND), U4.4 (GND), U4.6 (GND), U4.7 (GND), U5.4 (GND), U5.6 (GND), U5.7 (GND), U6.2 (GND), U6.5 (GND), U6.6 (GND), U7.1 (GND), U7.6 (GND), U7.8 (GND), U7.9 (GND), U7.11 (GND), U7.12 (GND), U7.15 (GND), U7.19 (GND), U7.21 (GND), U7.22 (GND), U7.27 (GND), U7.28 (GND), U7.29 (PAD), U8.2 (GND), U8.9 (GND), U9.2 (GND), U9.9 (GND), U11.12 (VSSA), U11.18 (VSS), U11.31 (VSS), U11.47 (VSS), U11.63 (VSS), U12.2 (GND), X1.2 (GND), X2.2 (GND)
LED1: R9.2, U1.12 (P0_6)
LED2: R10.2, U1.13 (P0_7)
LST_RESET: J1.6, R3.1, R5.2, U11.20 (PA4)
unnamed: C11.2, R2.2
unnamed: C17.1, FB2.1, R19.1
unnamed: C34.1, U6.1
unnamed: C42.1, R24.2, R25.1
unnamed: C47.1, R26.2, R27.1
unnamed: D1.2 (A), R9.1
unnamed: D2.2 (A), R10.1
unnamed: D5.2 (A), R28.1
unnamed: D6.2 (A), R29.1
unnamed: D7.2 (A), R30.1
unnamed: D8.2 (A), R31.1
unnamed: D9.2 (A), R32.1
unnamed: J3.2, R14.2
unnamed: J4.2, R18.2
unnamed: C36.2, J5.1 (In)
unnamed: J6.2, U4.2 (V1)
unnamed: J6.3, R21.2
unnamed: C37.2, J7.1 (In)
unnamed: J13.A5 (CC1_A), R37.1
unnamed: J13.B5 (CC2_B), R38.2
unnamed: R12.2, TP1.1
unnamed: C15.1, U1.30 (DCOUPL)
unnamed: R4.1, U1.14 (P2_0)
unnamed: R1.1, U1.17 (P2_3/XOSC32-1)
unnamed: R7.2, U1.27 (RBIAS)
unnamed: C14.2, R5.1, U1.31 (RESET_N), U2.2 (RESET)
unnamed: R2.1, U1.21 (XOSC-1)
unnamed: C37.1, U4.5 (RF1)
unnamed: C32.1, U4.8 (RF2)
unnamed: C34.2, U4.3 (RFC)
unnamed: C29.1, FB3.1, U4.1 (V2)
unnamed: C35.1, U5.5 (RF1)
unnamed: C33.1, U5.8 (RF2)
unnamed: C32.2, U5.3 (RFC)
unnamed: C31.1, FB4.1, U5.1 (V2)
unnamed: C36.1, U7.7 (ANT)
unnamed: C33.2, U7.18 (RX)
unnamed: U3.5 (RF), U7.10 (SAW1)
unnamed: U3.2 (RF), U7.13 (SAW2)
unnamed: C35.2, U7.20 (TX)
unnamed: R33.1, SW2.4, U11.60 (PH3_BOOT0)
unnamed: C11.1, X1.3 (OUT)
PROG_DC: J1.3, U1.16 (P2_2)
PROG_DD: J1.4, U1.15 (P2_1)

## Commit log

2021-08-30 Add new RF Frontend & other changes in progress
    [openlst-hw.sch]
2021-10-17 Completed schematic, going to layout
    [openlst-hw.sch]
2021-11-17 Radio board done, except for artwork touchup
    [bom.csv, bom_grouped.csv, openlst-hw.kicad_pcb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]
2021-11-20 Final before gerbers are generated
    [bom.csv, bom_grouped.csv, openlst-hw.kicad_pcb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]
2021-11-20 touchup fill missing via after reviewing gerbers
    [openlst-hw.kicad_pcb]
2021-11-20 Add Gerbers
    [openlst-hw-B.Cu.gbl, openlst-hw-B.Mask.gbs, openlst-hw-B.Paste.gbp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]
2021-11-25 F Paste gerber
2024-08-18 upgrade to KICAD 8, change power converters and auxiliarry pin connectors
    [openlst-hw.kicad_pcb]
2024-08-18 change footprint to 80x80mm to fit cubesat 1U more comfortabley
    [openlst-hw.kicad_pcb, openlst-hw.kicad_sch]
2024-08-20 add CAN bridge, change bus connector from 2x20 to 2x24 to allow second can bus and battery
    [openlst-hw.kicad_pcb, openlst-hw.kicad_sch]
2024-08-21 cleanup, logical arrangement of connectors, short paths where possible and step files for all components
    [openlst-hw.kicad_pcb, openlst-hw.kicad_sch, power.kicad_sch]
2024-08-24 break out RF part to separate schema, update BOM
    [JS202011JCQN.step, LGA-28-6x6-0.7x0.7.step, openlst-hw.kicad_pcb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]
2024-08-24 further refactor schema into subsheets
    [MCU.kicad_sch, openlst-hw.kicad_pcb, openlst-hw.kicad_sch]
2024-08-25 automatic schematic and pcb valiadation and cleanup
    [MCU.kicad_sch, openlst-hw.kicad_pcb, openlst-hw.kicad_sch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]
2024-09-13 cleanup openlst board after connector update
    [openlst-hw.kicad_pcb, openlst-hw.kicad_sch]
2024-09-14 flip can high low around to ease access from front side
    [openlst-hw.kicad_pcb, openlst-hw.kicad_sch]
2024-09-23 temporary branch for radio to pc104
    [MCU.kicad_sch, can_bridge.kicad_sch, openlst-hw.kicad_sch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]
2024-09-24 use Common libraries, replace TI MCU with STM32 for CAN bridge
    [MCU.kicad_sch, can_bridge.kicad_sch, openlst-hw.kicad_pcb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]
2024-09-24 integrated stm32 as CAN bridge and pc104 bus
    [openlst-hw.kicad_pcb]
2024-09-30 AVI light sensors with i2c multiplexers for AVI board. i2c amp/volt meter for attitude control coils
    [openlst-hw.kicad_sch]
2024-10-02 openlst board to updated pc104 layout
    [MCU.kicad_sch, openlst-hw.kicad_pcb, openlst-hw.kicad_sch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]
2024-10-02 replacd TJA1042 with TCAN3414 that allows differential from 3V, negating the need for 5V generator
    [can_bridge.kicad_sch, openlst-hw.kicad_pcb, stm32_pmic.kicad_sch]
